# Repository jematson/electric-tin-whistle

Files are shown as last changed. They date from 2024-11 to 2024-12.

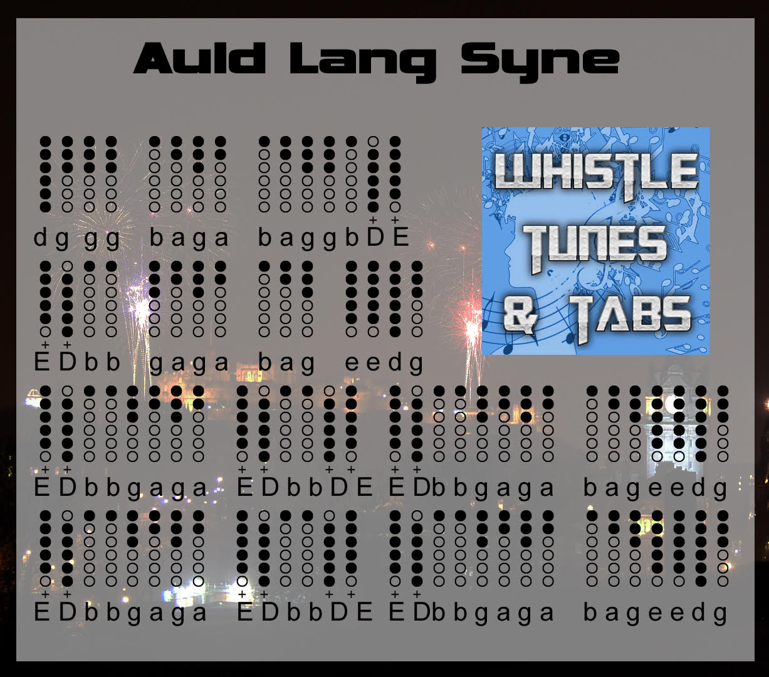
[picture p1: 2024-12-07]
auld_lang_syne_tabs.jpg

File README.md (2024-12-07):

# Electric Tin Whistle
#### By Jenae Matson

This repository assembles the code, stl files, and documentation to create an electric tin whistle. The electric tin whistle is an electric instrument 
that mimics the [tin whistle](https://en.wikipedia.org/wiki/Tin_whistle), a simple woodwind instrument. This can be used as an education project to learn about
programming an Arduino Nano, soldering, digital music synthesis, and how to use components such as a breath sensor and headphone jack. 

This project was created with a mini grant from the T3 Makerspace at the University of Alaska Fairbanks.

## Components
This project requires the following parts and components:
- 1 [Arduino Nano](https://www.amazon.com/gp/product/B086GNYXPH/ref=ppx_yo_dt_b_search_asin_title?ie=UTF8&th=1)
- 1 [digital pressure sensor](https://www.amazon.com/dp/B0CDWX82PT?ref=ppx_yo2ov_dt_b_fed_asin_title)
- 1 [3.5mm audio jack](https://www.amazon.com/Gikfun-Breakout-Headphone-Arduino-AE1223/dp/B01KFP0HBG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)
- 1 [prototype board](https://www.amazon.com/ElectroCookie-Solderable-Breadboards-Gold-Plated-Multi-Pack/dp/B07ZV9JQY2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)
- 6 [button switches](https://www.amazon.com/Gikfun-12x12x7-3-Tactile-Momentary-Arduino/dp/B01E38OS7K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)
- 1 [slide switch](https://www.amazon.com/Switch-SPDT-Micro-Breadboard-GuuYebe/dp/B0CRTPY88B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)
- [Breadboard jumper wires](https://www.amazon.com/Breadboard-Minidodoca-Magnetic-Assortment-Alligator/dp/B0BFX352X6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)
- 1 [4 AA battery holder](https://www.amazon.com/LAMPVPATH-Battery-Holder-Bundle-Arduino/dp/B07BNN9PDF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)
- 1 10kΩ resistor
- Breadboard
- Earbuds
- PLA Filament
- Computer with [Arduino IDE](https://www.arduino.cc/en/software)

## Assembly Instructions
1. Using the wiring diagram and component configuration, assemble the electric tin whistle on the breadboard.

   a. You can connect components to different Arduino pins than the wiring diagram indicates if it will better optimize the wiring. Make sure to change these pins in the code later.
2. Flash the breath_sensor_testing.ino code to the Arduino Nano

   a. With this code running, you can establish the lower and mid pressure thresholds. Looking at the Serial Plotter graph, try blowing into the pressure sensor. The lower threshold should be a pressure value slightly above the rest value, and the mid threshold should be about halfway between the rest pressure and the maximum blowing pressure.
3. Flash the electric_tin_whistle.ino code to the Arduino Nano

   a. Test the system. If things aren't working, you can use the commented testing code at the bottom of the file to test the buttons and headphone jack and figure out what is wrong.

   b. If you changed any pin wiring from the wiring diagram, make sure to change the pin declarations in the code.
4. Once you are sure all the parts are working correctly, you can begin soldering parts to the prototype board.

   a. Use electrical tape to hold parts in place.
5. Once the system is soldered together, test again.
6. Print the case and mouthpiece.

   a. You may need to file down parts of the case to make the two halves fit together.
7. Assemble and play!

   a. The tin whistle fingering diagram and example song tabs above can help you get started. 

### Component Configuration
- Arduino Nano: E49-63 & I49-63
- Air pressure sensor: H1-4
- Buttons: 
  - D42, D40, G42, G40
  - D36, D34, G36, G34
  - D30, D28, G30, G28
  - D24, D22, G24, G22
  - D18, D16, G18, G16
  - D12, D10, G12, G10
- Power switch: J43-45
- Audio jack: A44-47

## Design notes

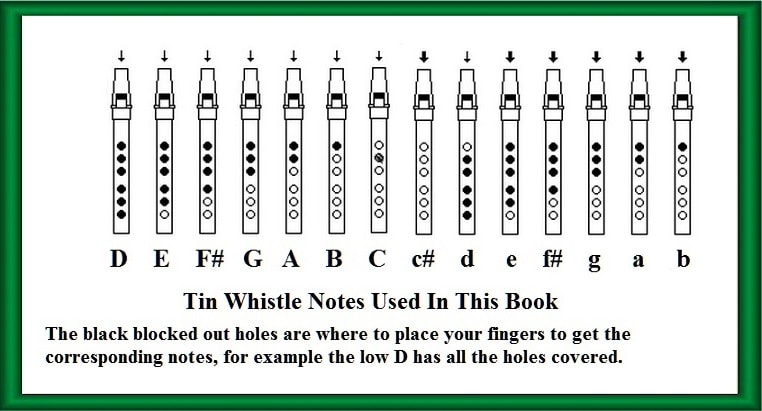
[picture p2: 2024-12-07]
tin_whistle_fingering.jpg

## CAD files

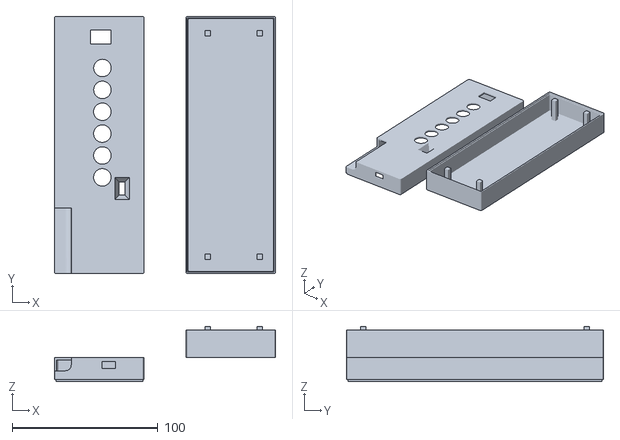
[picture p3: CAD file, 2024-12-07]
etw_case.stl
151.5 x 176.3 x 38.0

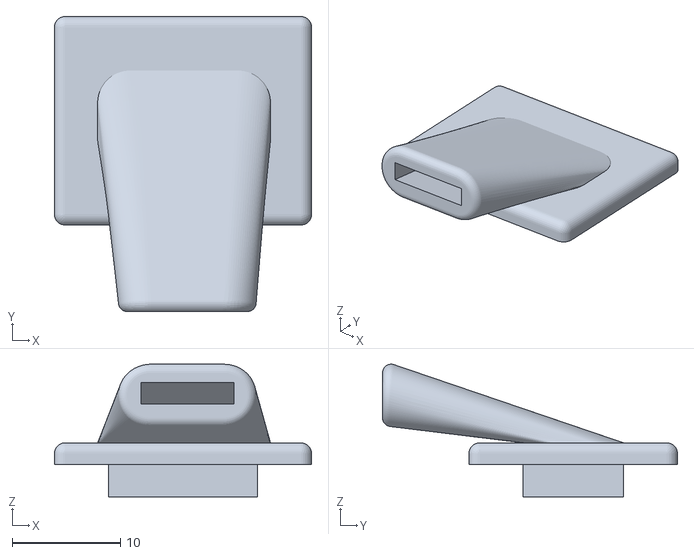
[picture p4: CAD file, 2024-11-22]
etw_mouthpiece.stl
23.8 x 27.3 x 12.3

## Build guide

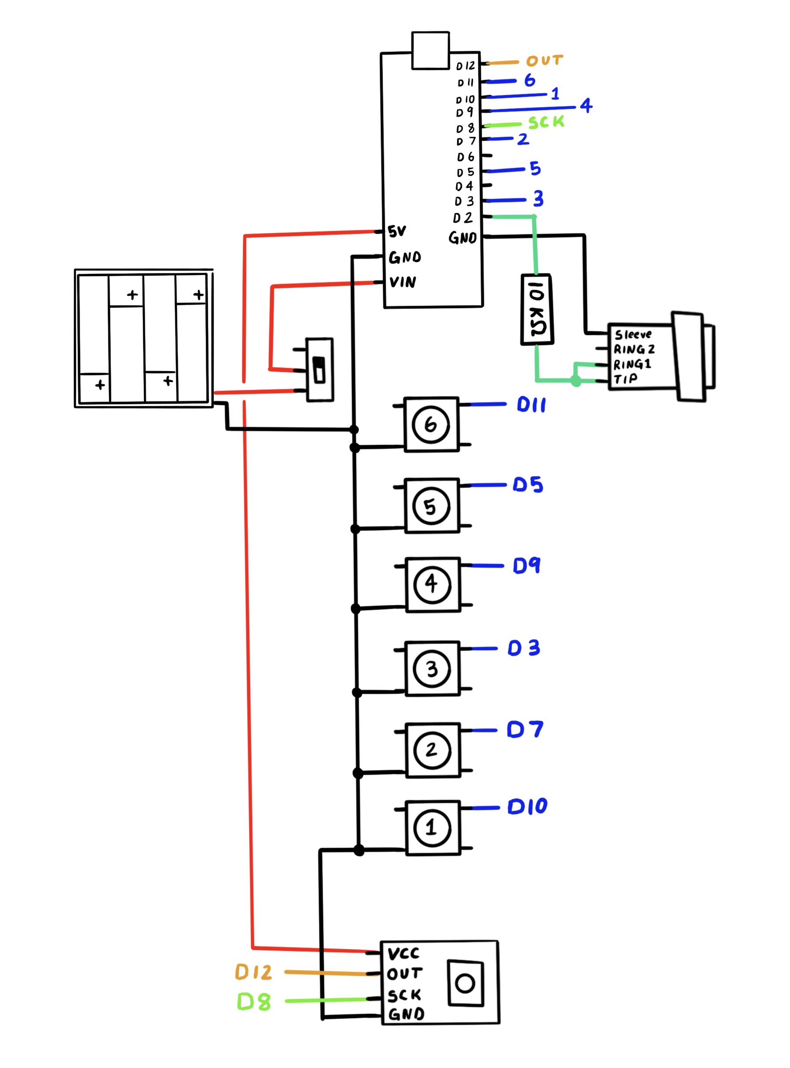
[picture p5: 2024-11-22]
wiring_diagram.jpg

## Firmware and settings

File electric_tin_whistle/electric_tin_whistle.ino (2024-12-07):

/*
  Electric Tin Whistle Code
  by Jenae Matson
  Description: Code for an electric tin whistle instrument using an Arduino Nano.
*/

// Assign frequency values to musical notes
typedef enum {
  D = 294,
  E = 330,
  F = 370,
  G = 392, 
  A = 440,
  B = 494,
  C = 523,
  c = 554,
  d = 587,
  e = 659,
  f = 740,
  g = 784,
  a = 880,
  b = 988
} notes;

// Define lower pressure values for low/high octaves
const int low_threshold = 1050;
const int mid_threshold = 1200;

// Pin declarations
const int hole1 = 10;
const int hole2 = 7;
const int hole3 = 3;
const int hole4 = 9;
const int hole5 = 5;
const int hole6 = 11;
const int sound = 2;
const int clkOut = 12;
const int clkIn = 8;

// Initialize the pressure sensor value
unsigned long sensorValue = 0;

void setup() {
  Serial.begin(57600);
  Serial.println("Starting up...");
  pinMode(hole1, INPUT_PULLUP);
  pinMode(hole2, INPUT_PULLUP);
  pinMode(hole3, INPUT_PULLUP);
  pinMode(hole4, INPUT_PULLUP);
  pinMode(hole5, INPUT_PULLUP);
  pinMode(hole6, INPUT_PULLUP);
  pinMode(clkOut, INPUT_PULLUP);
  pinMode(clkIn, OUTPUT);
  pinMode(sound, OUTPUT);
  Serial.println("Setup done...");
}

void loop() {
  // Get the current pressure sensor input
  unsigned long currPressure = sensorToPressure();
  Serial.println(currPressure);

  // Check buttons and play corresponding notes
  if (currPressure > low_threshold && currPressure < mid_threshold) {   // only play notes if the play button is down
    //Serial.println("low octave");
    if (check_pin(hole1) && check_pin(hole2) && check_pin(hole3) && check_pin(hole4) && check_pin(hole5) && check_pin(hole6)) { // D
      tone(sound, D);
    } else if (check_pin(hole1) && check_pin(hole2) && check_pin(hole3) && check_pin(hole4) && check_pin(hole5)) {  // E
      tone(sound, E);
    } else if (check_pin(hole1) && check_pin(hole2) && check_pin(hole3) && check_pin(hole4)) {  // F#
      tone(sound, F);
    } else if (check_pin(hole1) && check_pin(hole2) && check_pin(hole3)) {  // G
      tone(sound, G);
    } else if (check_pin(hole1) && check_pin(hole2)) {  // A
      tone(sound, A);
    } else if (check_pin(hole1)) {  // B
      tone(sound, B);
    } else if (check_pin(hole2) && check_pin(hole3)) {  // C
      tone(sound, C);
    } else if (!check_pin(hole1) && !check_pin(hole2) && !check_pin(hole3) && !check_pin(hole4) && !check_pin(hole5) && !check_pin(hole6)) {  // c#
      tone(sound, c);
    } else {
      noTone(sound);
    }
  } else if(currPressure >= mid_threshold) {
    if (!check_pin(hole1) && !check_pin(hole2) && !check_pin(hole3) && !check_pin(hole4) && !check_pin(hole5) && !check_pin(hole6)) { // D
      tone(sound, c);
    } else if(check_pin(hole2) && check_pin(hole3) && check_pin(hole4) && check_pin(hole5) && check_pin(hole6)) { // d
      tone(sound, d);
    } else if(check_pin(hole1) && check_pin(hole2) && check_pin(hole3) && check_pin(hole4) && check_pin(hole5)) { // e
      tone(sound, e);
    } else if(check_pin(hole1) && check_pin(hole2) && check_pin(hole3) && check_pin(hole4)) { // f#
      tone(sound, f);
    } else if(check_pin(hole1) && check_pin(hole2) && check_pin(hole3)) { // g
      tone(sound, g);
    } else if(check_pin(hole1) && check_pin(hole2)) { // a
      tone(sound, a);
    } else if(check_pin(hole1)) { // b
      tone(sound, b);
    } else {
      noTone(sound);
    }
  } else {
    noTone(sound);
  }
}

// Check if the given button is being pressed down
bool check_pin(const int pin) {
  if(!digitalRead(pin)){
    return true;
  } else {
    return false;
  }
}

// Pulse one 
void pulse() {
  digitalWrite(clkIn, LOW);
  digitalWrite(clkIn, HIGH);
  digitalWrite(clkIn, LOW);
}

// Get the current pressure sensor reading
unsigned long sensorToPressure() {
  sensorValue = 0; // clear sensor data
  while(!(digitalRead(clkOut) == LOW)); // wait for out to be low, data ready
  for (int i = 0; i < 24; i++) {
    pulse();
    sensorValue <<= 1; // shift left by 1 bit
    if(digitalRead(clkOut)) {
      sensorValue |= 1;
    }
  }
  pulse();
  //sensorValue -= 886000;
  //sensorValue = (sensorValue * 100) / 40000;
  sensorValue /= 1000;
  return sensorValue;
}

// System Testing

// Check buttons
/*
  if (check_pin(hole1)) {
    Serial.println("hole1");
  } else if (check_pin(hole2)) {
    Serial.println("hole2");
  } else if (check_pin(hole3)) {
    Serial.println("hole3");
  } else if (check_pin(hole4)) {
    Serial.println("hole4");
  } else if (check_pin(hole5)) {
    Serial.println("hole5");
  } else if (check_pin(hole6)) {
    Serial.println("hole6");
  }
*/

// Check a single octave
/*
  if (check_pin(hole1) && check_pin(hole2) && check_pin(hole3) && check_pin(hole4) && check_pin(hole5) && check_pin(hole6)) { // D
    tone(sound, D);
    Serial.println("D");
  } else if (check_pin(hole1) && check_pin(hole2) && check_pin(hole3) && check_pin(hole4) && check_pin(hole5)) {  // E
    tone(sound, E);
    Serial.println("E");
  } else if (check_pin(hole1) && check_pin(hole2) && check_pin(hole3) && check_pin(hole4)) {  // F#
    tone(sound, F);
    Serial.println("F");
  } else if (check_pin(hole1) && check_pin(hole2) && check_pin(hole3)) {  // G
    tone(sound, G);
    Serial.println("G");
  } else if (check_pin(hole1) && check_pin(hole2)) {  // A
    tone(sound, A);
    Serial.println("A");
  } else if (check_pin(hole1)) {  // B
    tone(sound, B);
    Serial.println("B");
  } else if (check_pin(hole2) && check_pin(hole3)) {  // C
    tone(sound, C);
    Serial.println("C");
  } else if (!check_pin(hole1) && !check_pin(hole2) && !check_pin(hole3) && !check_pin(hole4) && !check_pin(hole5) && !check_pin(hole6)) {  // c#
    //tone(sound, c);
  } else {
    noTone(sound);
  }
*/

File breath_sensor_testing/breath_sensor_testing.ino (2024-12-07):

const int clkOut = 12; //4
const int clkIn = 8; //3

unsigned long sensorValue = 0;

void pulse() {
  digitalWrite(clkIn, LOW);
  digitalWrite(clkIn, HIGH);
  digitalWrite(clkIn, LOW);
}

bool outLow() {
  return digitalRead(clkOut) == LOW;
}

unsigned long readSensor() {
  sensorValue = 0; // clear sensor data
  while(!outLow()); // wait for out to be low, data ready
  for (int i = 0; i < 24; i++) {
    pulse();
    sensorValue <<= 1; // shift left by 1 bit
    if(digitalRead(clkOut)) {
      sensorValue |= 1;
    }
  }
  pulse();
  return sensorValue;
}

void setup() {
  Serial.begin(57600);
  pinMode(clkOut, INPUT_PULLUP);
  pinMode(clkIn, OUTPUT);
}

void loop() {
  unsigned long pressure = readSensor();
  //pressure -= 886000;
  //pressure = (pressure * 100) / 40000;
  pressure /= 1000;
  Serial.println(pressure);
  delay(100);
}

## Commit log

2024-11-22 Add Arduino and STL files
    [etw_case.stl, etw_mouthpiece.stl]
2024-11-22 Add wiring diagram
2024-11-22 Upload corrected STL for the mouthpiece
    [etw_mouthpiece.stl]
2024-12-07 Update sensor thresholds in code
2024-12-07 Update stl file and add musical resources
    [etw_case.stl]
